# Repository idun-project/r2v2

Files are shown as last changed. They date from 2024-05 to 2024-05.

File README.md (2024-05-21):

## R2V2 - Dual-video switcher & converter for the Commodore 128

This is an open-source project that aims to improve the quality, flexibility, and convenience of the dual-video outputs of the Commodore 128.

In the normal configuration, the C128 has two independent video outputs for the VDC (80-column mode) and the VIC-II (40-column mode) displays. Each display requires its own cable going to its own specific type of monitor input, with the ideal being RGBI input for the 80col display and S-video for the 40col display. You can use two monitors, or you can use a retro monitor (e.g. Commodore 1084) that is manually switchable between two inputs.

With R2V2 installed in a C128, a single port, cable, and monitor input is used for BOTH display modes AND the display mode is switchable using the keyboard or with software control. If you also have the [idun-cartridge](https://github.com/idun-project/idun-cartridge), its software will be able to switch the displays automatically.

### Components

VDC Enhancer (8568) front
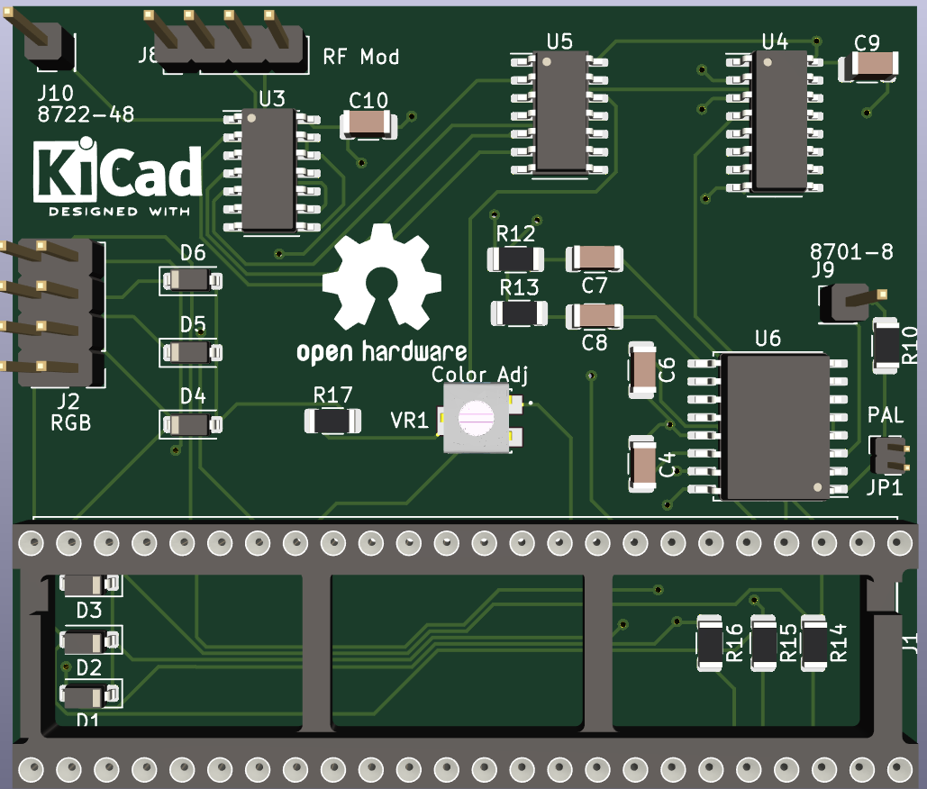
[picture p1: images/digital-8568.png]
VDC enhancer front


VDC Enhancer (8563) back
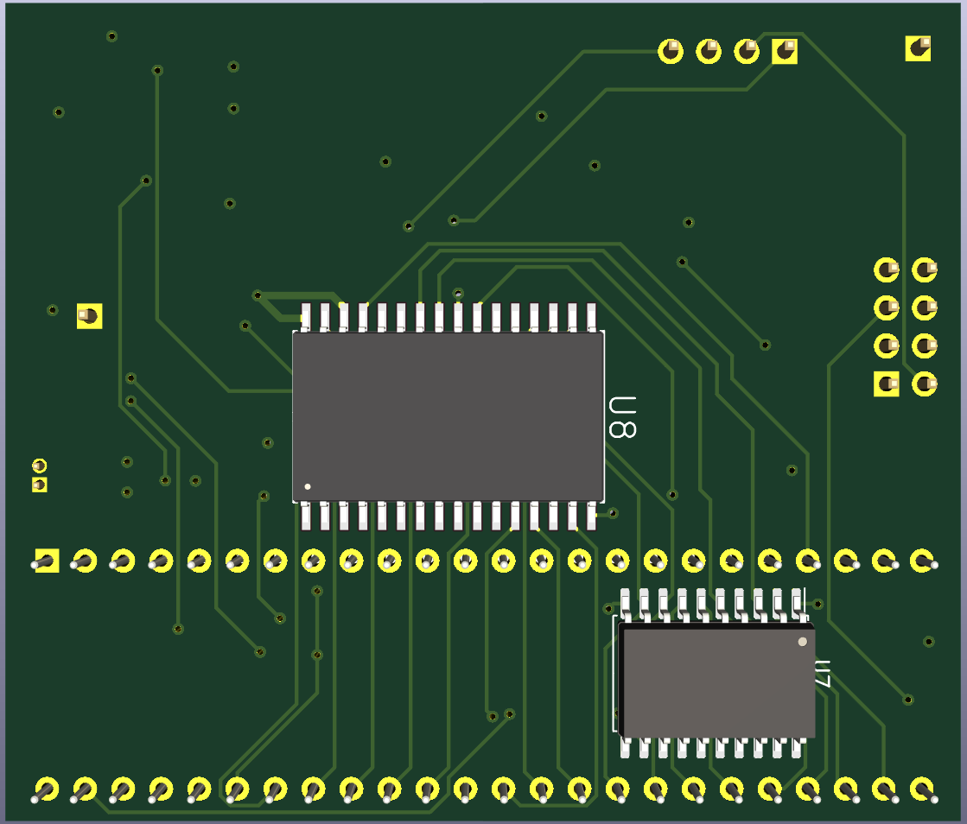
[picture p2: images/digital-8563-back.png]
VDC enhancer back


R2V2 requires two small PCBs installed internally. One sits under the VDC chip, and can optionally include 64KB video RAM expanasion. There are versions for the MOS8563 and the MOS8568 (for C128-DCR). The second PCB installed is from the breakable PCB pictured and is either:

1. An RF modulator replacement, which enhances the 8-pin DIN monitor port plus adds composite monitor and stereo audio outputs (supports 2 SIDs). It can also support switchable **HDMI OUT** from the composite port! (Requires additional components)
2. A modification for the DB-9 monitor port, which outputs analog RGB (rather than RGBI) and can also be used for switchable **HDMI OUT**.

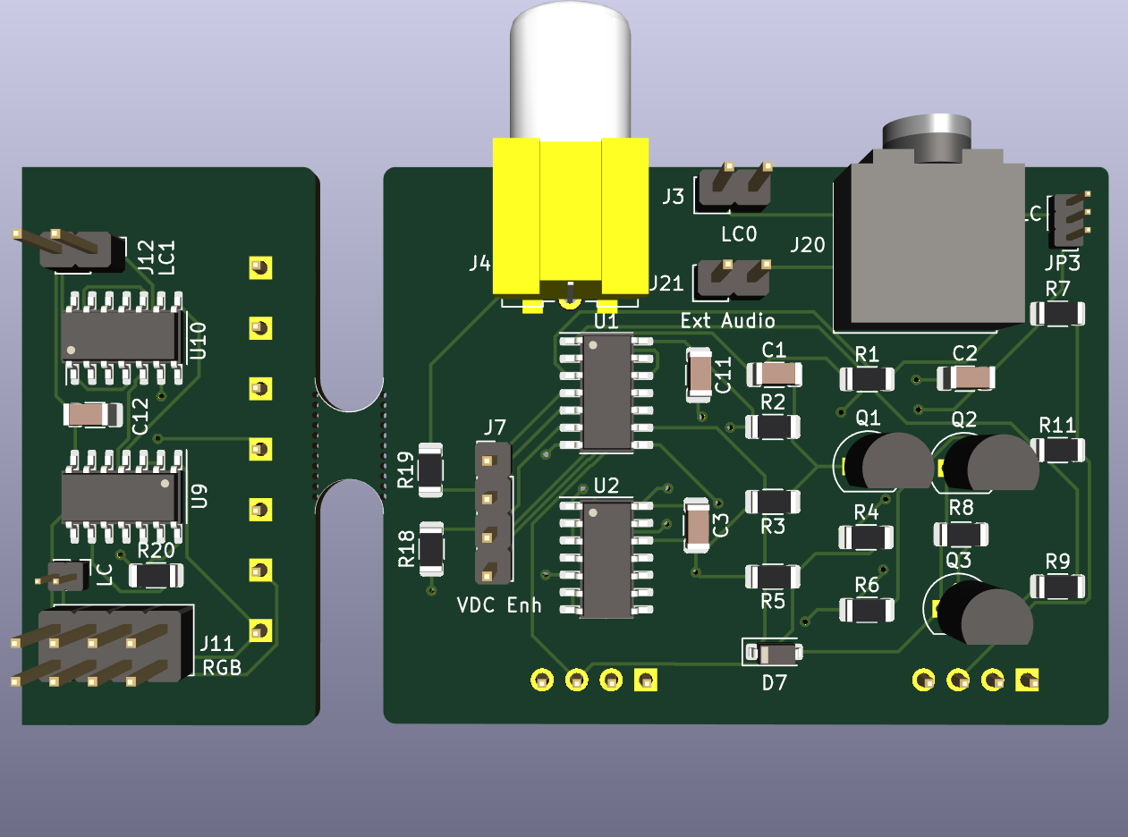
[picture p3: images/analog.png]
2-part analog PCB


### Status

This is an open-source project still in the R&D phase. It is not fully baked, and you should not try to build it _unless you want to contribute to the testing/debugging effort_.

- [x] Prototype PCBs manufactured
    - [x] MOS8568 VDC enhancer
    - [x] MOS8563 VDC enhancer
    - [x] analog board
- [ ] Prototype PCBs assembled
    - [ ] MOS8568 VDC enhancer
    - [ ] MOS8563 VDC enhancer w/o SRAM
    - [ ] MOS8563 VDC enhancer w/ SRAM
    - [ ] RF modulator replacement
    - [ ] DB-9 mod
- [ ] Testing
    - [ ] MOS8568+RF mod S-vid, composite, audio
    - [ ] MOS8563+RF mod S-vid, composite, audio
    - [ ] MOS8563+SRAM
    - [ ] MOS8563+RF mod LumaCode, mono-80c to RGBtoHDMI
    - [ ] MOS8568+DB-9 mod analog RGB
    - [ ] MOS8568+DB-9 mod LumaCode, color-80c to RGBtoHDMI
    - [ ] MOS8563+DB-9 mod LumaCode, color-80c to RGBtoHDMI

### Configurations

Many different configurations are possible, and depends on the kind of monitor you want to use, be it a retro CRT, modern monitor with analog input, or HDMI.

#### For analog monitor inputs

If you intend to use a monitor that supports S-video, you should be able to get good quality color output for both 80col and 40col display modes. Install the VDC enhancer compatible to your system and the RF modulator replacement, then connect the DIN monitor port to your display. You can use the audio on the DIN port, or plug in to the 3.5mm headphone jack.

If you intend to use a monitor that supports composite, you can get decent color 40col and monochrome 80col from the output on the RCA jack. Install the VDC enhancer and the RF modulator replacement, then connect the composite output to your display. Most likely, you will want to use the 3.5mm heahphone jack for audio.

It is possible to install both the RF modulator replacement and the DB-9 mod. If you do this, then you'll have analog RGB (both RGBS and RGBHV) on the DB-9, and that might be what you want for some monitors (e.g. SCART input). You'll have to work out your own switching between displays using this configuration.

#### For digital HDMI monitors

For the absolute best picture quality on modern displays, the R2V2 is combined with the [VIC-II LumaCode](https://github.com/c0pperdragon/LumaCode/wiki/VICIIdizer128-(for-the-C128)) enhancement and an external [RGBtoHDMI](https://github.com/hoglet67/RGBtoHDMI/wiki) video converter/upscaler.

There is a simpler version of the RGBtoHDMI designed by "C0pperdragon" that handles only LumaCode and monochrome video. This version can be used with the composite output on the RF modulator replacement. You will get color 40col and monochrome 80col display modes from a single HDMI input.

If you want the best HDMI experience with color 80col, then you'll need the more sophisticated RGBtoHDMI converter that handles both LumaCode and RGBS. This version connects with a custom cable to the DB-9 port and uses LumaCode for 40col mode and RGBS for 80col mode.

_NOTE_: A firmware patch and profile for the RGBtoHDMI is being developed so that it will automatically switch display modes as your C128 switches between 40/80col modes.

#### 64KB video RAM

The C128-DCR uses a MOS8568 VDC and came with 64KB of VRAM. Just use the MOS8568 version VDC enhancer and you're all set.

Other models of the C128 use a MOS8563 VDC and came with 16KB of VRAM. You must use the MOS8563 version VDC enhancer, and you can _optionally_ install 2 chips on the back of the PCB to upgrade to 64KB of VRAM.

### Build Instructions

TO BE CONTINUED...

### Installation Instructions

TO BE CONTINUED...

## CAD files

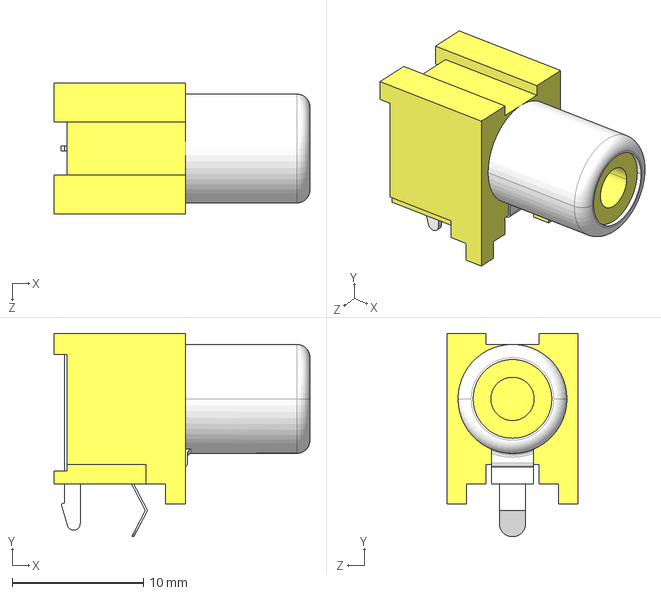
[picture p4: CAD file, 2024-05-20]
r2v2-analog/r2v2_proj_models/CUI_DEVICES_RCJ-044.step
19.5 x 15.5 x 10.0 mm

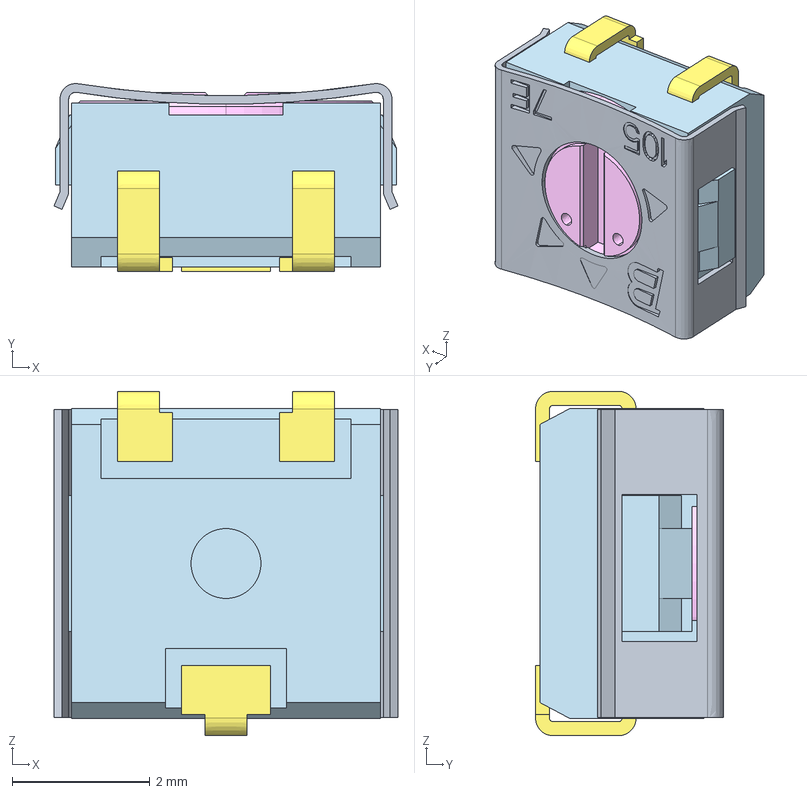
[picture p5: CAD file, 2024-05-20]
r2v2-analog/r2v2_proj_models/3314J-1-501E.step
5.00 x 2.73 x 5.00 mm

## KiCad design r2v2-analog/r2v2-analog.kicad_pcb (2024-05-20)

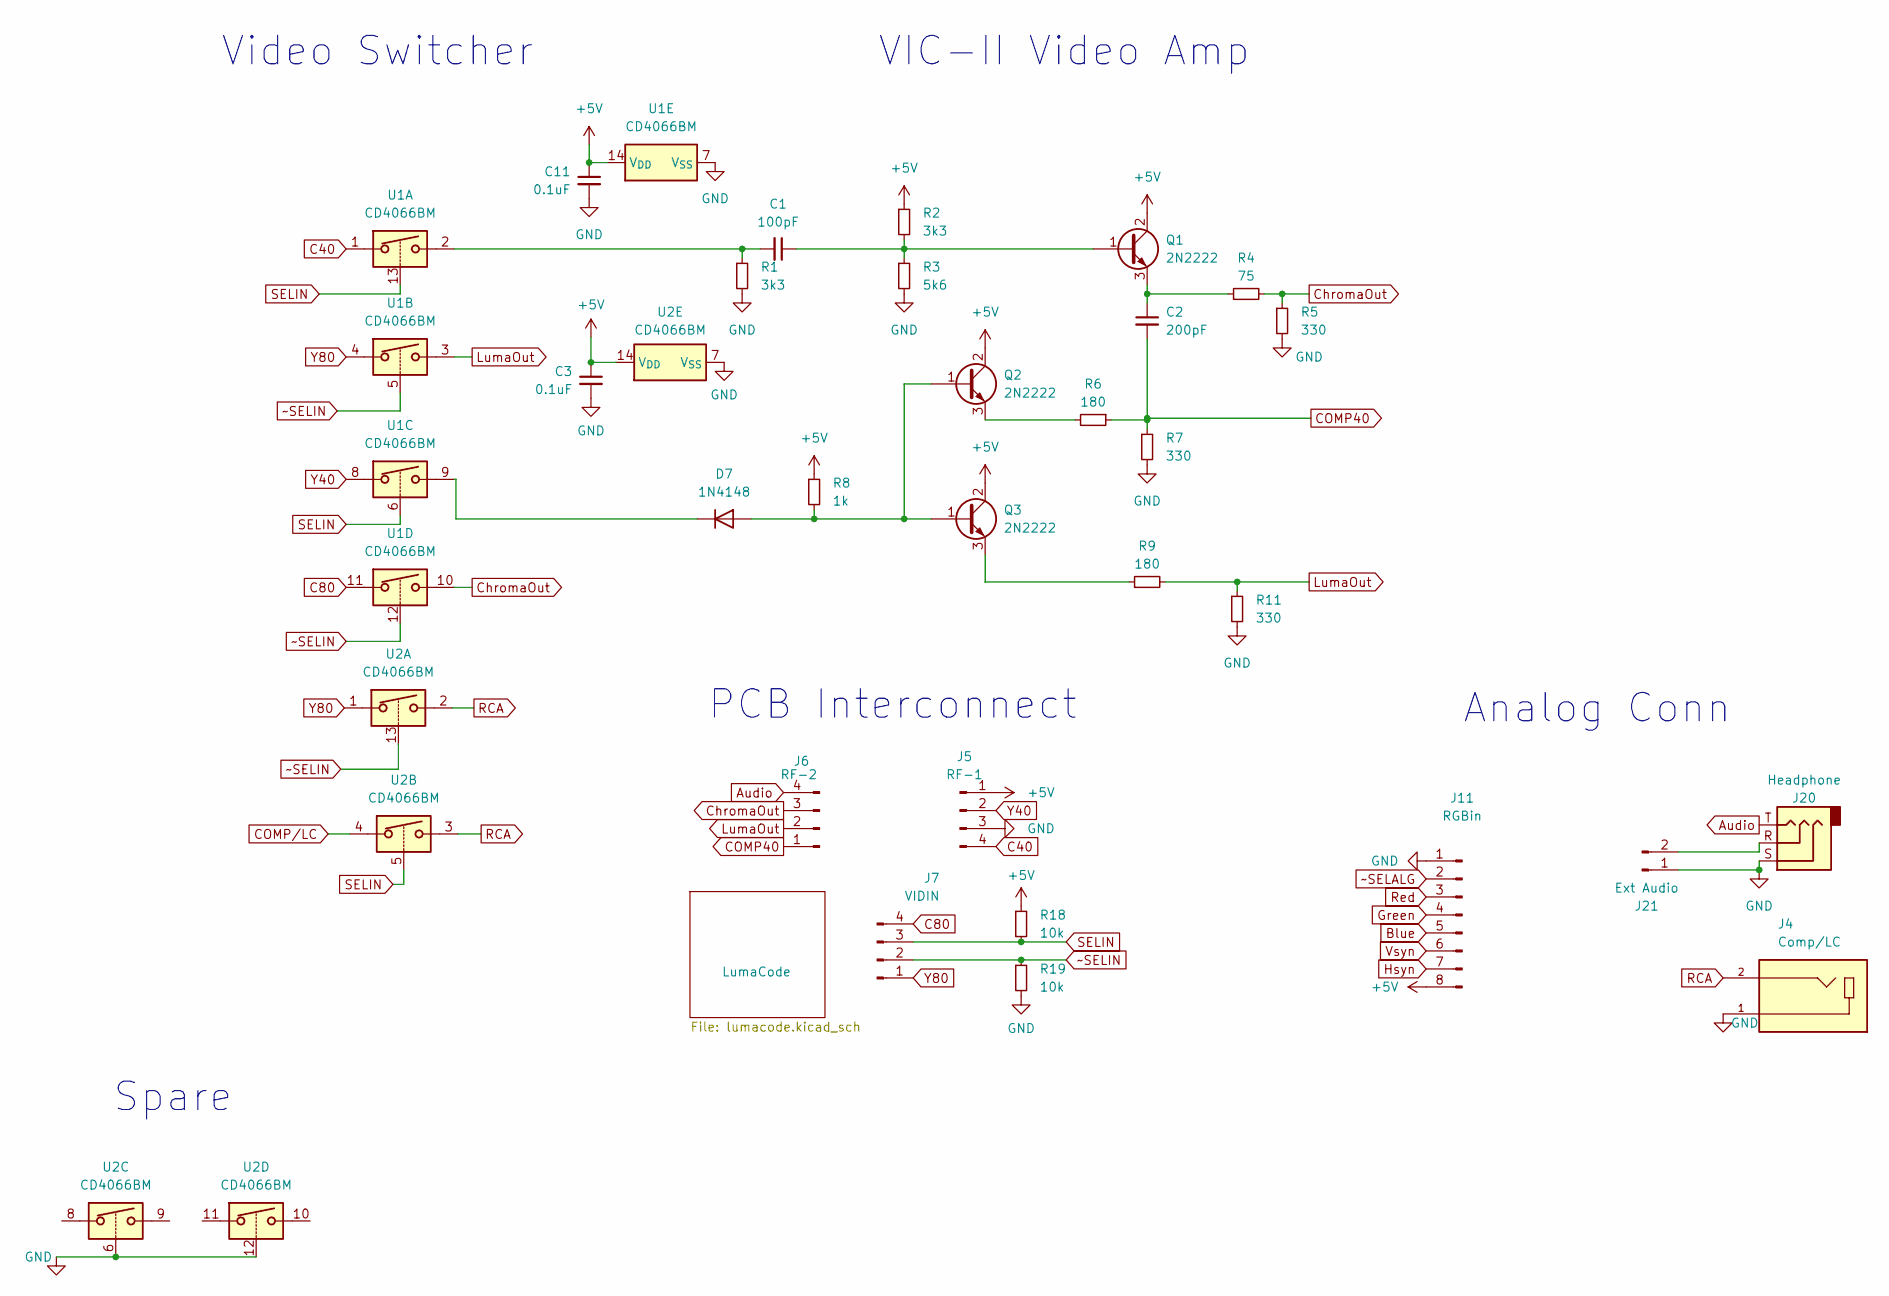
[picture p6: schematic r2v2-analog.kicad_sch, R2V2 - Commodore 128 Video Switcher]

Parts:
C1: 100pF; C_1206_3216Metric
C2: 200pF; C_1206_3216Metric
C3, C11: 0.1uF; C_1206_3216Metric
D7: 1N4148; D_SOD-123
J4: Comp/LC; CUI_RCJ-044; PARTREV 1.02
J5: RF-1; PinHeader_1x04_P2.54mm_Vertical
J6: RF-2; PinHeader_1x04_P2.54mm_Vertical
J7: VIDIN; PinHeader_1x04_P2.54mm_Vertical
J11: RGBin; PinHeader_2x04_P2.54mm_Vertical
J20: Headphone; Jack_3.5mm_CUI_SJ1-3523N_Horizontal
J21: Ext Audio; PinHeader_1x02_P2.54mm_Vertical
Q1, Q2, Q3: 2N2222; TO-92
R1, R2: 3k3; R_1206_3216Metric
R3: 5k6; R_1206_3216Metric
R4: 75; R_1206_3216Metric
R5, R7, R11: 330; R_1206_3216Metric
R6, R9: 180; R_1206_3216Metric
R8: 1k; R_1206_3216Metric
R18, R19: 10k; R_1206_3216Metric
U1, U2: CD4066BM; SO-14_3.9x8.65mm_P1.27mm

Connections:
+5V: C3.1, C11.1, J5.1, J11.8, Q1.2 (C), Q2.2 (C), Q3.2 (C), R2.1, R8.1, R18.1, U1.14 (V_{DD}), U2.14 (V_{DD}); also elsewhere on the board
Audio: J6.4, J20.T
Blue: J11.5; also elsewhere on the board
C40: J5.4, U1.1
C80: J7.4, U1.11
COMP40: C2.2, J6.1, R6.1, R7.1; also elsewhere on the board
COMP/LC: U2.4; also elsewhere on the board
ChromaOut: J6.3, R4.2, R5.1, U1.10
GND: C3.2, C11.2, J4.1, J5.3, J11.1, J20.S, J21.1, R1.2, R3.2, R5.2, R7.2, R11.2, R19.2, U1.7 (V_{SS}), U2.6, U2.7 (V_{SS}), U2.12; also elsewhere on the board
Green: J11.4; also elsewhere on the board
Hsyn: J11.7; also elsewhere on the board
LumaOut: J6.2, R9.2, R11.1, U1.3
unnamed: C1.2, R1.1, U1.2
unnamed: D7.2 (A), Q2.1 (B), Q3.1 (B), R8.2
unnamed: D7.1 (K), U1.9
unnamed: J20.R, J21.2
unnamed: C1.1, Q1.1 (B), R2.2, R3.1
unnamed: C2.1, Q1.3 (E), R4.1
unnamed: Q2.3 (E), R6.2
unnamed: Q3.3 (E), R9.1
RCA: J4.2, U2.2, U2.3
Red: J11.3; also elsewhere on the board
SELIN: J7.3, R18.2, U1.6, U1.13, U2.5
Vsyn: J11.6; also elsewhere on the board
Y40: J5.2, U1.8
Y80: J7.1, U1.4, U2.1
~SELALG: J11.2; also elsewhere on the board
~SELIN: J7.2, R19.1, U1.5, U1.12, U2.13

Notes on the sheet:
Spare
VIC-II Video Amp
Video Switcher
Analog Conn
PCB Interconnect

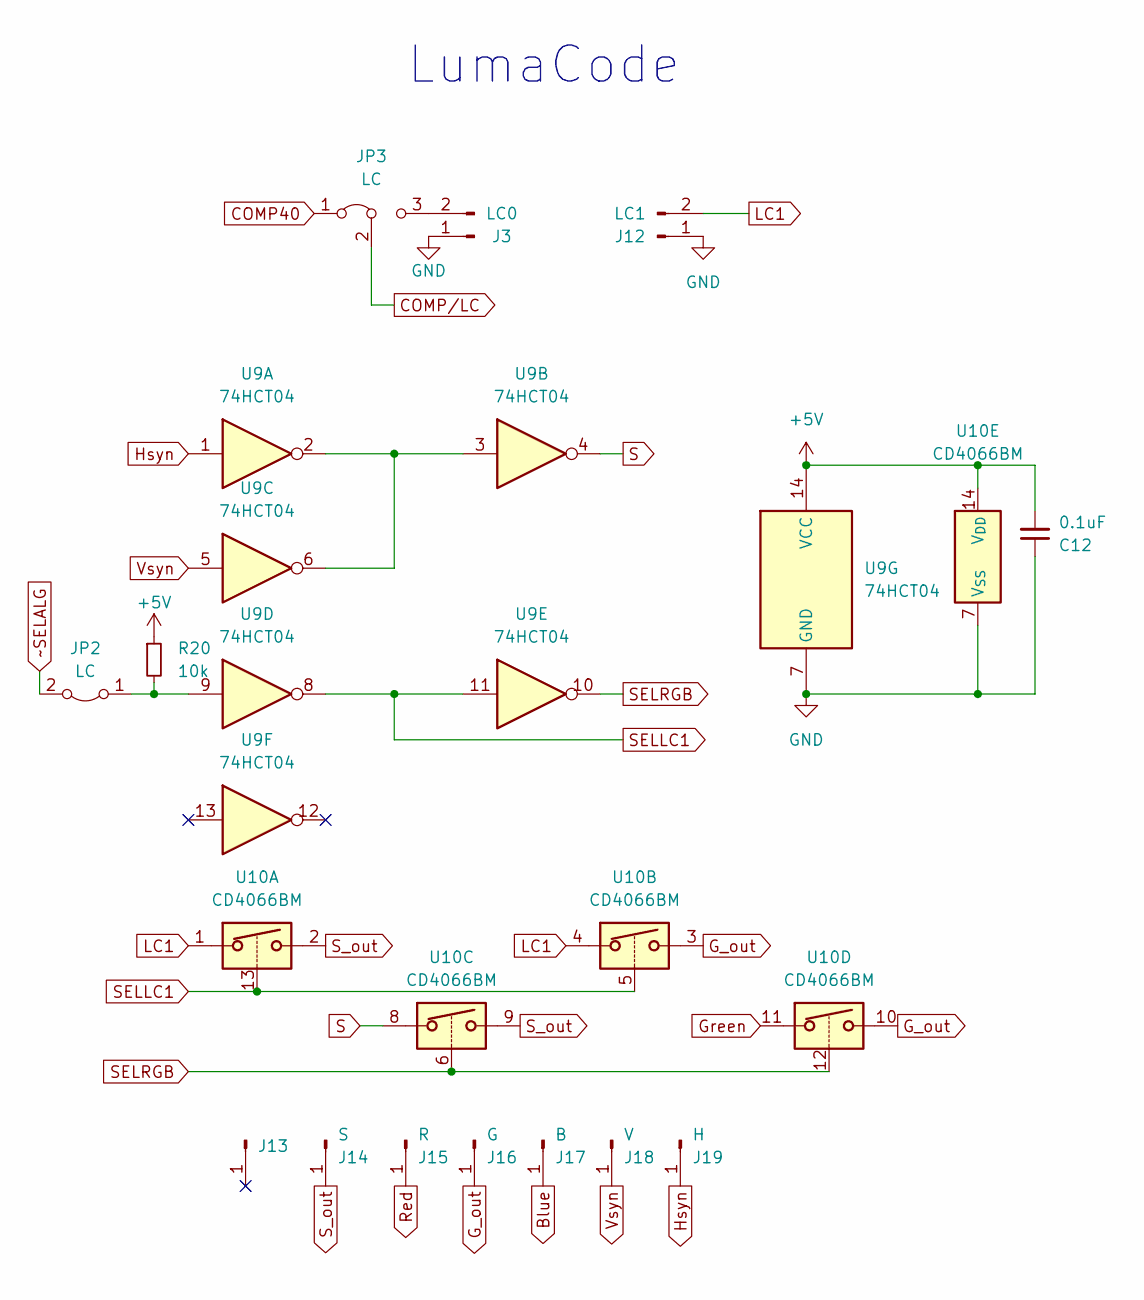
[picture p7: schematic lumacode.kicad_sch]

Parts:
C12: 0.1uF; C_1206_3216Metric
J3: LC0; PinHeader_1x02_P2.54mm_Vertical
J12: LC1; PinHeader_1x02_P2.54mm_Vertical
J13: PinHeader_1x01_P2.54mm_Vertical
J14: S; PinHeader_1x01_P2.54mm_Vertical
J15: R; PinHeader_1x01_P2.54mm_Vertical
J16: G; PinHeader_1x01_P2.54mm_Vertical
J17: B; PinHeader_1x01_P2.54mm_Vertical
J18: V; PinHeader_1x01_P2.54mm_Vertical
J19: H; PinHeader_1x01_P2.54mm_Vertical
JP2: LC; PinHeader_1x02_P1.27mm_Vertical
JP3: LC; PinHeader_1x03_P1.27mm_Vertical
R20: 10k; R_1206_3216Metric
U9: 74HCT04; SO-14_3.9x8.65mm_P1.27mm
U10: CD4066BM; SO-14_3.9x8.65mm_P1.27mm

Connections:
+5V: C12.2, R20.1, U9.14 (VCC), U10.14 (V_{DD}); also elsewhere on the board
Blue: J17.1; also elsewhere on the board
COMP40: JP3.1 (A); also elsewhere on the board
COMP/LC: JP3.2 (C); also elsewhere on the board
GND: C12.1, J3.1, J12.1, U9.7 (GND), U10.7 (V_{SS}); also elsewhere on the board
G_out: J16.1, U10.3, U10.10
Green: U10.11; also elsewhere on the board
Hsyn: J19.1, U9.1; also elsewhere on the board
LC1: J12.2, U10.1, U10.4
unnamed: J3.2, JP3.3 (B)
unnamed: JP2.1 (A), R20.2, U9.9
unnamed: U9.2, U9.3, U9.6
Red: J15.1; also elsewhere on the board
S: U9.4, U10.8
SELLC1: U9.8, U9.11, U10.5, U10.13
SELRGB: U9.10, U10.6, U10.12
S_out: J14.1, U10.2, U10.9
Vsyn: J18.1, U9.5; also elsewhere on the board
~SELALG: JP2.2 (B); also elsewhere on the board

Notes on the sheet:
LumaCode

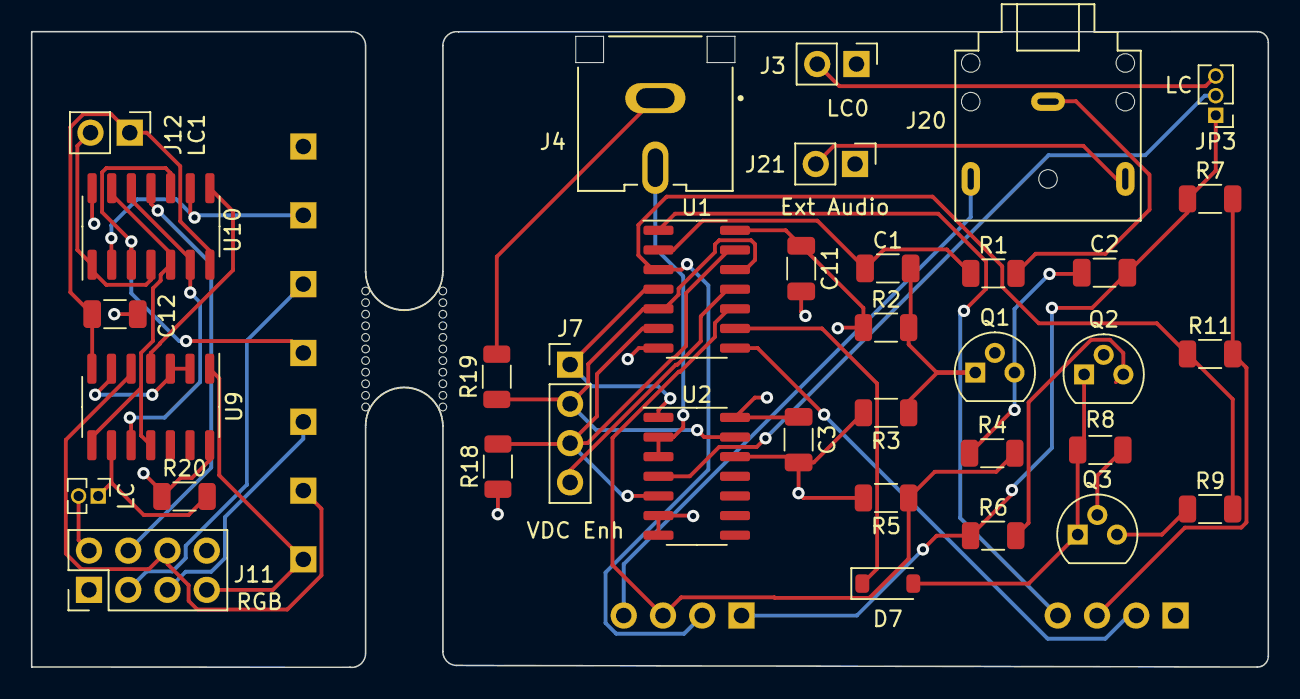
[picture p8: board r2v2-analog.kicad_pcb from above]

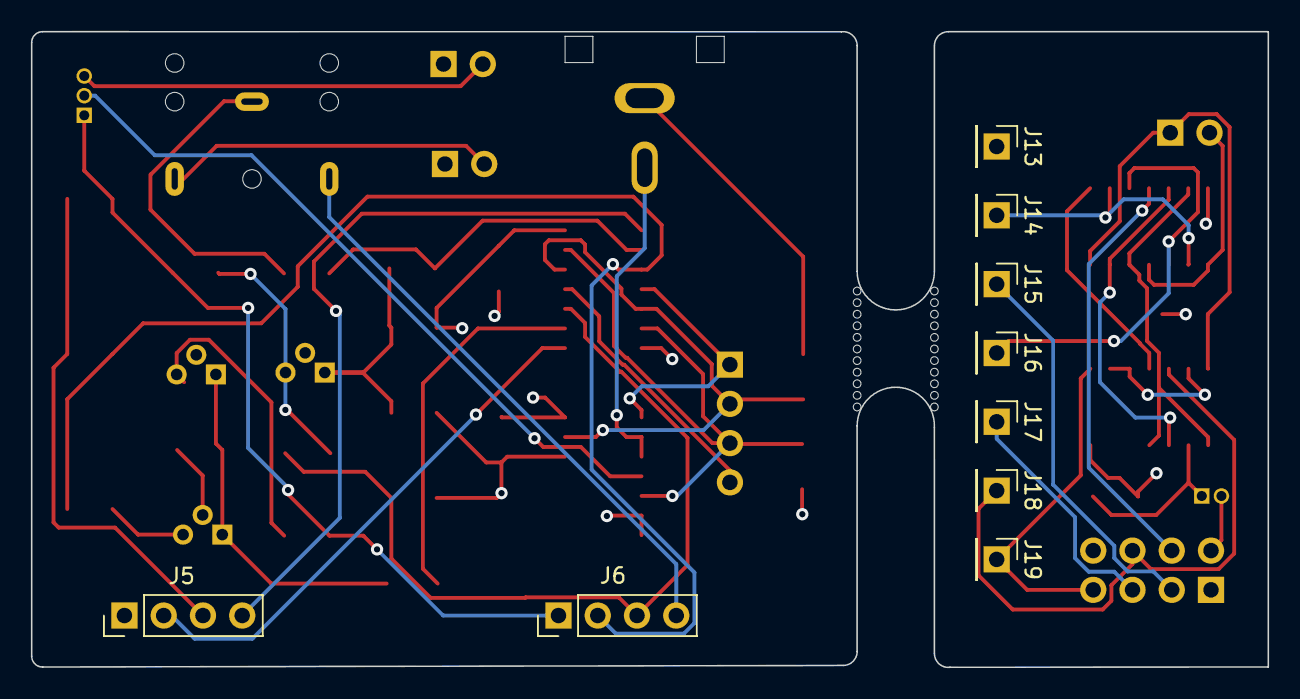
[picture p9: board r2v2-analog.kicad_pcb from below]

Board: 4 copper layers, 80.0 x 41.1 mm, 45 parts (9 on the bottom side), 37 nets.

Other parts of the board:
mouse-bite-5mm-slot: VAL**; mouse-bite-5mm-slot

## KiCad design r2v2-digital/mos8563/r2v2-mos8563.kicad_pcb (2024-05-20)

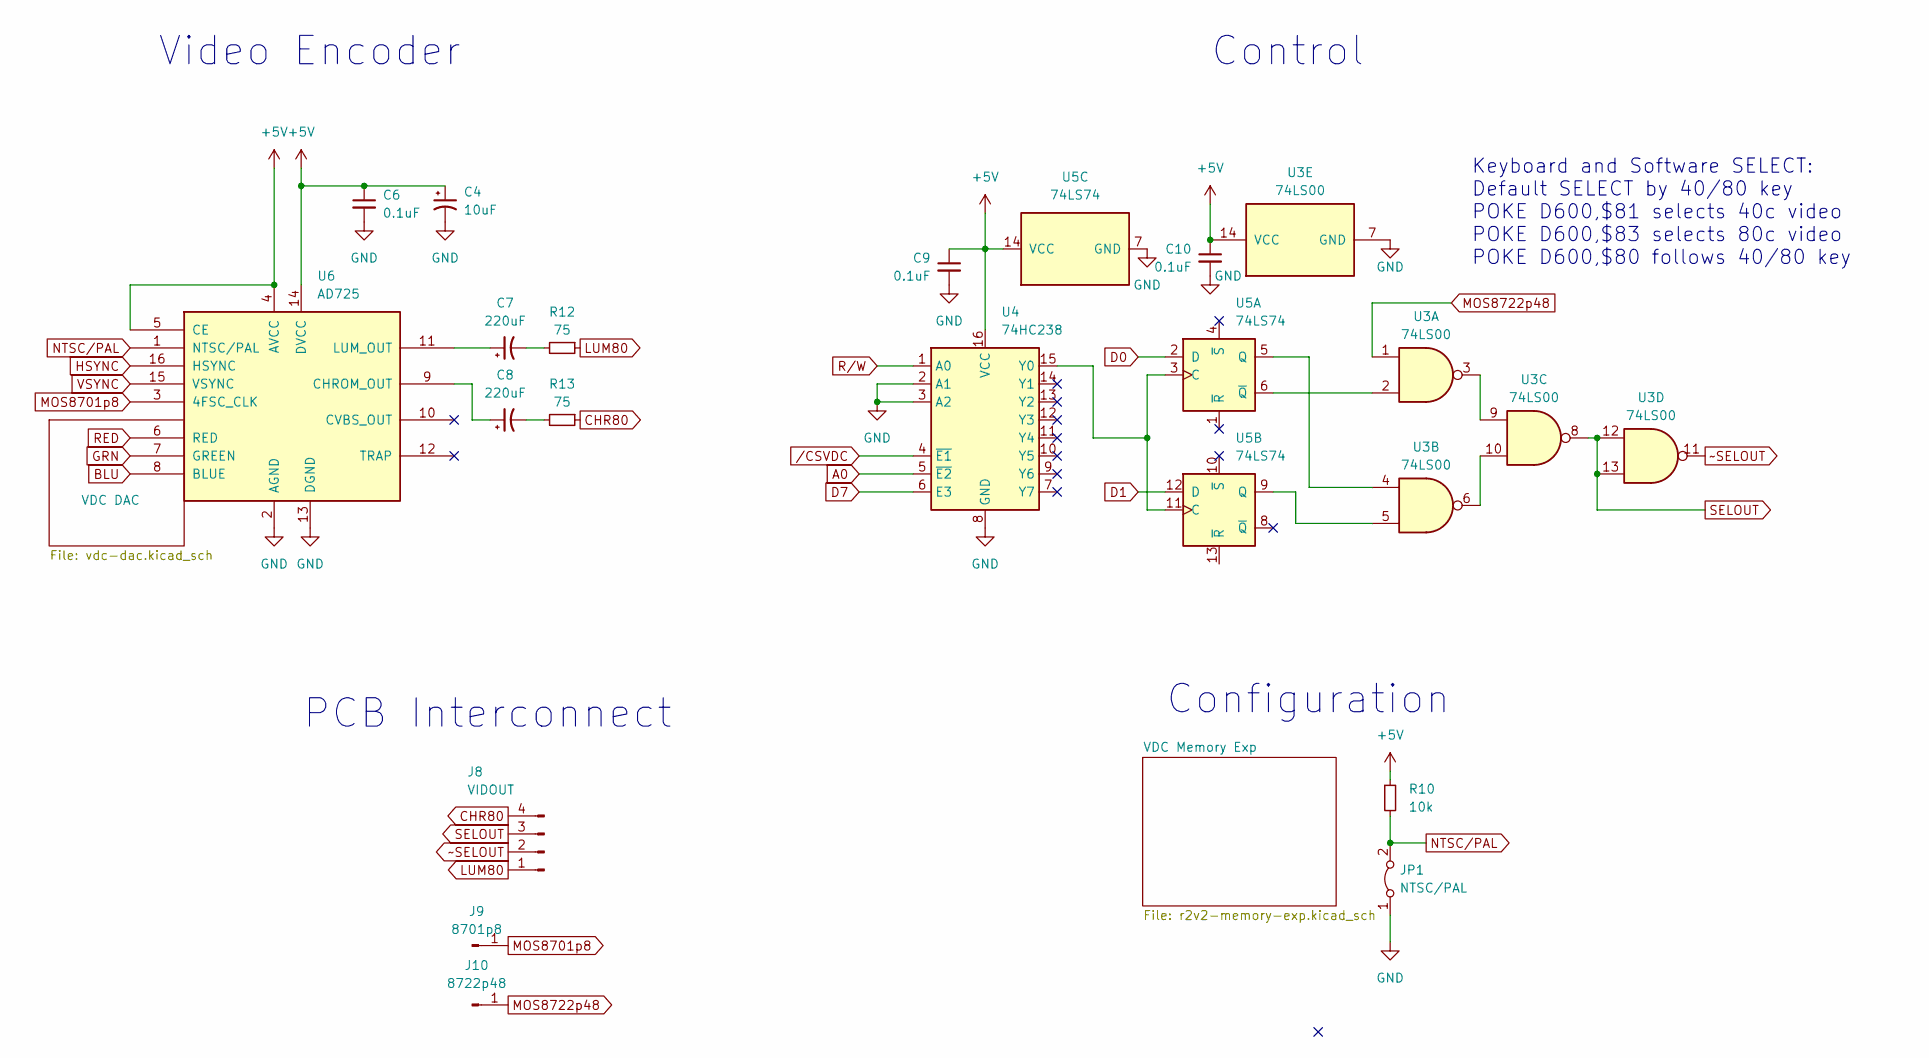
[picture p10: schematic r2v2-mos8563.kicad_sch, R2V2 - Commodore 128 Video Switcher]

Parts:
C4: 10uF; C_1206_3216Metric
C6, C9, C10: 0.1uF; C_1206_3216Metric
C7, C8: 220uF; C_1206_3216Metric
J8: VIDOUT; PinHeader_1x04_P2.54mm_Vertical
J9: 8701p8; PinHeader_1x01_P2.54mm_Vertical
J10: 8722p48; PinHeader_1x01_P2.54mm_Vertical
JP1: NTSC/PAL; PinHeader_1x02_P1.27mm_Vertical
R10: 10k; R_1206_3216Metric
R12, R13: 75; R_1206_3216Metric
U3: 74LS00; SOIC-14_3.9x8.7mm_P1.27mm
U4: 74HC238; SOIC-16_3.9x9.9mm_P1.27mm
U5: 74LS74; SO-14_3.9x8.65mm_P1.27mm
U6: AD725; SOIC-16W_7.5x10.3mm_P1.27mm

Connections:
+5V: C4.1, C6.1, C9.1, C10.1, R10.1, U3.14 (VCC), U4.16 (VCC), U5.14 (VCC), U6.4 (AVCC), U6.5 (CE), U6.14 (DVCC); also elsewhere on the board
A0: U4.5 (~E2); also elsewhere on the board
BLU: U6.8 (BLUE); also elsewhere on the board
CHR80: J8.4, R13.1
D0: U5.2 (D); also elsewhere on the board
D1: U5.12 (D); also elsewhere on the board
D7: U4.6 (E3)
GND: C4.2, C6.2, C9.2, C10.2, JP1.1 (A), U3.7 (GND), U4.2 (A1), U4.3 (A2), U4.8 (GND), U5.7 (GND), U6.2 (AGND), U6.13 (DGND); also elsewhere on the board
GRN: U6.7 (GREEN); also elsewhere on the board
HSYNC: U6.16 (HSYNC); also elsewhere on the board
LUM80: J8.1, R12.1
MOS8701p8: J9.1, U6.3 (4FSC_CLK)
MOS8722p48: J10.1, U3.1
NTSC/PAL: JP1.2 (B), R10.2, U6.1 (NTSC/PAL)
unnamed: C7.2, R12.2
unnamed: C8.2, R13.2
unnamed: U3.3, U3.9
unnamed: U3.6, U3.10
unnamed: U4.15 (Y0), U5.3 (C), U5.11 (C)
unnamed: U3.4, U5.5 (Q)
unnamed: U3.2, U5.6 (~Q)
unnamed: U3.5, U5.9 (Q)
unnamed: C8.1, U6.9 (CHROM_OUT)
unnamed: C7.1, U6.11 (LUM_OUT)
RED: U6.6 (RED); also elsewhere on the board
R/W: U4.1 (A0); also elsewhere on the board
SELOUT: J8.3, U3.8, U3.12, U3.13
VSYNC: U6.15 (VSYNC); also elsewhere on the board
/CSVDC: U4.4 (~E1); also elsewhere on the board
~SELOUT: J8.2, U3.11; also elsewhere on the board

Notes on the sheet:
Control
Video Encoder
Keyboard and Software SELECT: Default SELECT by 40/80 key POKE D600,$81 selects 40c video POKE D600,$83 selects 80c video POKE D600,$80 follows 40/80 key
Configuration
PCB Interconnect

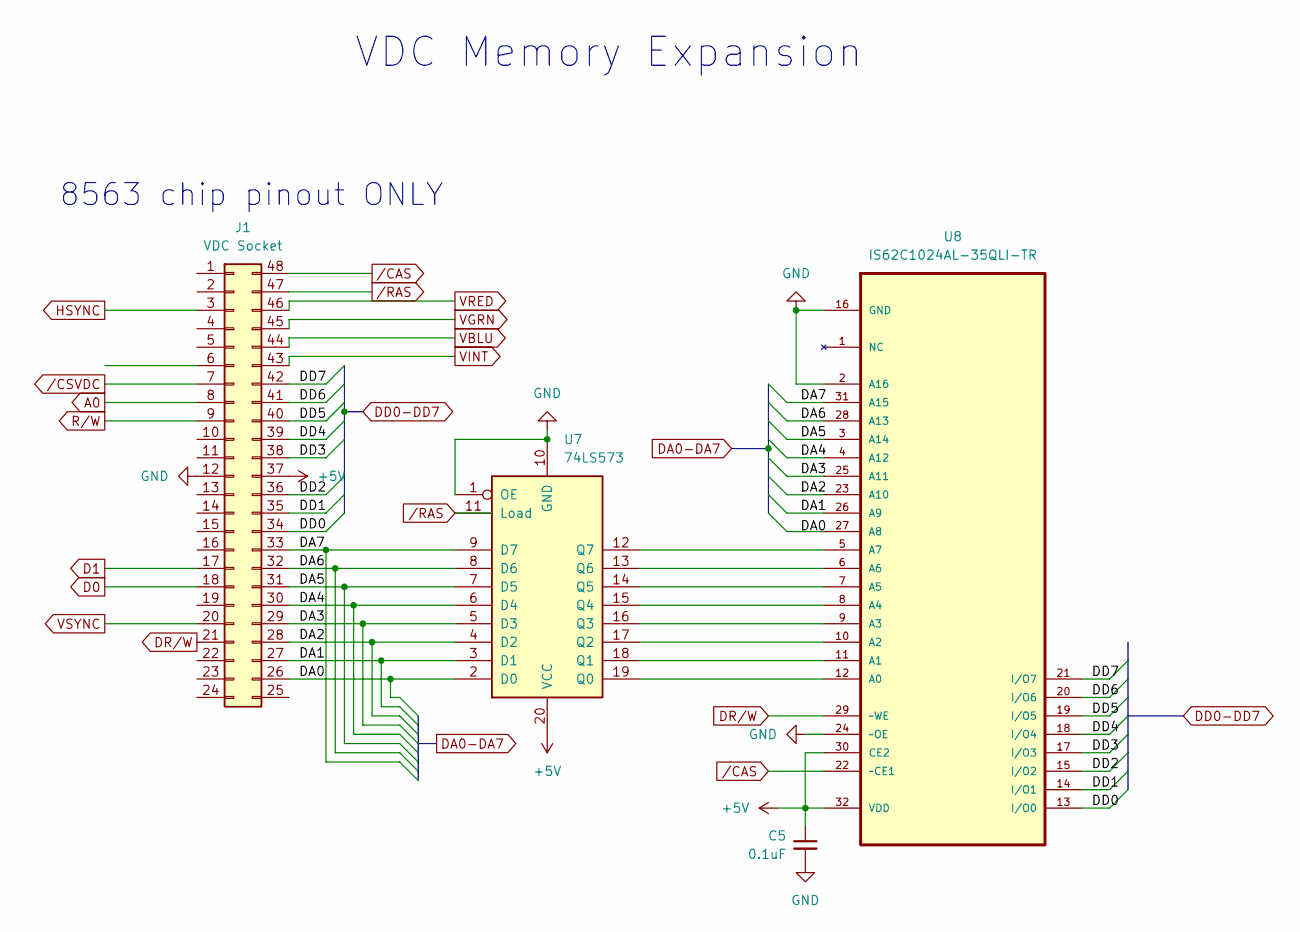
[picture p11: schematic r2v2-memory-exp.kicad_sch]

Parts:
C5: 0.1uF; C_1206_3216Metric
J1: VDC Socket; DIP-48_W15.24mm_Socket
U7: 74LS573; SOIC-20W_7.5x12.8mm_P1.27mm
U8: IS62C1024AL-35QLI-TR; SOIC127P1412X305-32N; MPN IS62C1024AL-35QLI-TR

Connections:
+5V: C5.1, J1.37, U7.20 (VCC), U8.30 (CE2), U8.32 (VDD); also elsewhere on the board
/VDC Memory Exp/DA0: J1.26, U7.2 (D0)
/VDC Memory Exp/DA1: J1.27, U7.3 (D1), U8.26 (A9)
/VDC Memory Exp/DA2: J1.28, U7.4 (D2), U8.23 (A10)
/VDC Memory Exp/DA3: J1.29, U7.5 (D3), U8.25 (A11)
/VDC Memory Exp/DA4: J1.30, U7.6 (D4), U8.4 (A12)
/VDC Memory Exp/DA5: J1.31, U7.7 (D5), U8.3 (A14)
/VDC Memory Exp/DA6: J1.32, U7.8 (D6), U8.28 (A13)
/VDC Memory Exp/DA7: J1.33, U7.9 (D7), U8.31 (A15)
/VDC Memory Exp/DD0: J1.34, U8.13 (I/O0)
/VDC Memory Exp/DD1: J1.35, U8.14 (I/O1)
/VDC Memory Exp/DD2: J1.36, U8.15 (I/O2)
/VDC Memory Exp/DD3: J1.38, U8.17 (I/O3)
/VDC Memory Exp/DD4: J1.39, U8.18 (I/O4)
/VDC Memory Exp/DD5: J1.40, U8.19 (I/O5)
/VDC Memory Exp/DD6: J1.41, U8.20 (I/O6)
/VDC Memory Exp/DD7: J1.42, U8.21 (I/O7)
A0: J1.8; also elsewhere on the board
D0: J1.18; also elsewhere on the board
D1: J1.17; also elsewhere on the board
DR/W: J1.21, U8.29 (~WE)
GND: C5.2, J1.12, U7.1 (OE), U7.10 (GND), U8.2 (A16), U8.16 (GND), U8.24 (~OE); also elsewhere on the board
HSYNC: J1.3; also elsewhere on the board
unnamed: U7.19 (Q0), U8.12 (A0)
unnamed: U7.18 (Q1), U8.11 (A1)
unnamed: U7.17 (Q2), U8.10 (A2)
unnamed: U7.16 (Q3), U8.9 (A3)
unnamed: U7.15 (Q4), U8.8 (A4)
unnamed: U7.14 (Q5), U8.7 (A5)
unnamed: U7.13 (Q6), U8.6 (A6)
unnamed: U7.12 (Q7), U8.5 (A7)
R/W: J1.9; also elsewhere on the board
VBLU: J1.44; also elsewhere on the board
VGRN: J1.45; also elsewhere on the board
VINT: J1.43; also elsewhere on the board
VRED: J1.46; also elsewhere on the board
VSYNC: J1.20; also elsewhere on the board
/CAS: J1.48, U8.22 (~CE1)
/CSVDC: J1.7; also elsewhere on the board
/RAS: J1.47, U7.11 (Load)

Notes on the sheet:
8563 chip pinout ONLY
VDC Memory Expansion

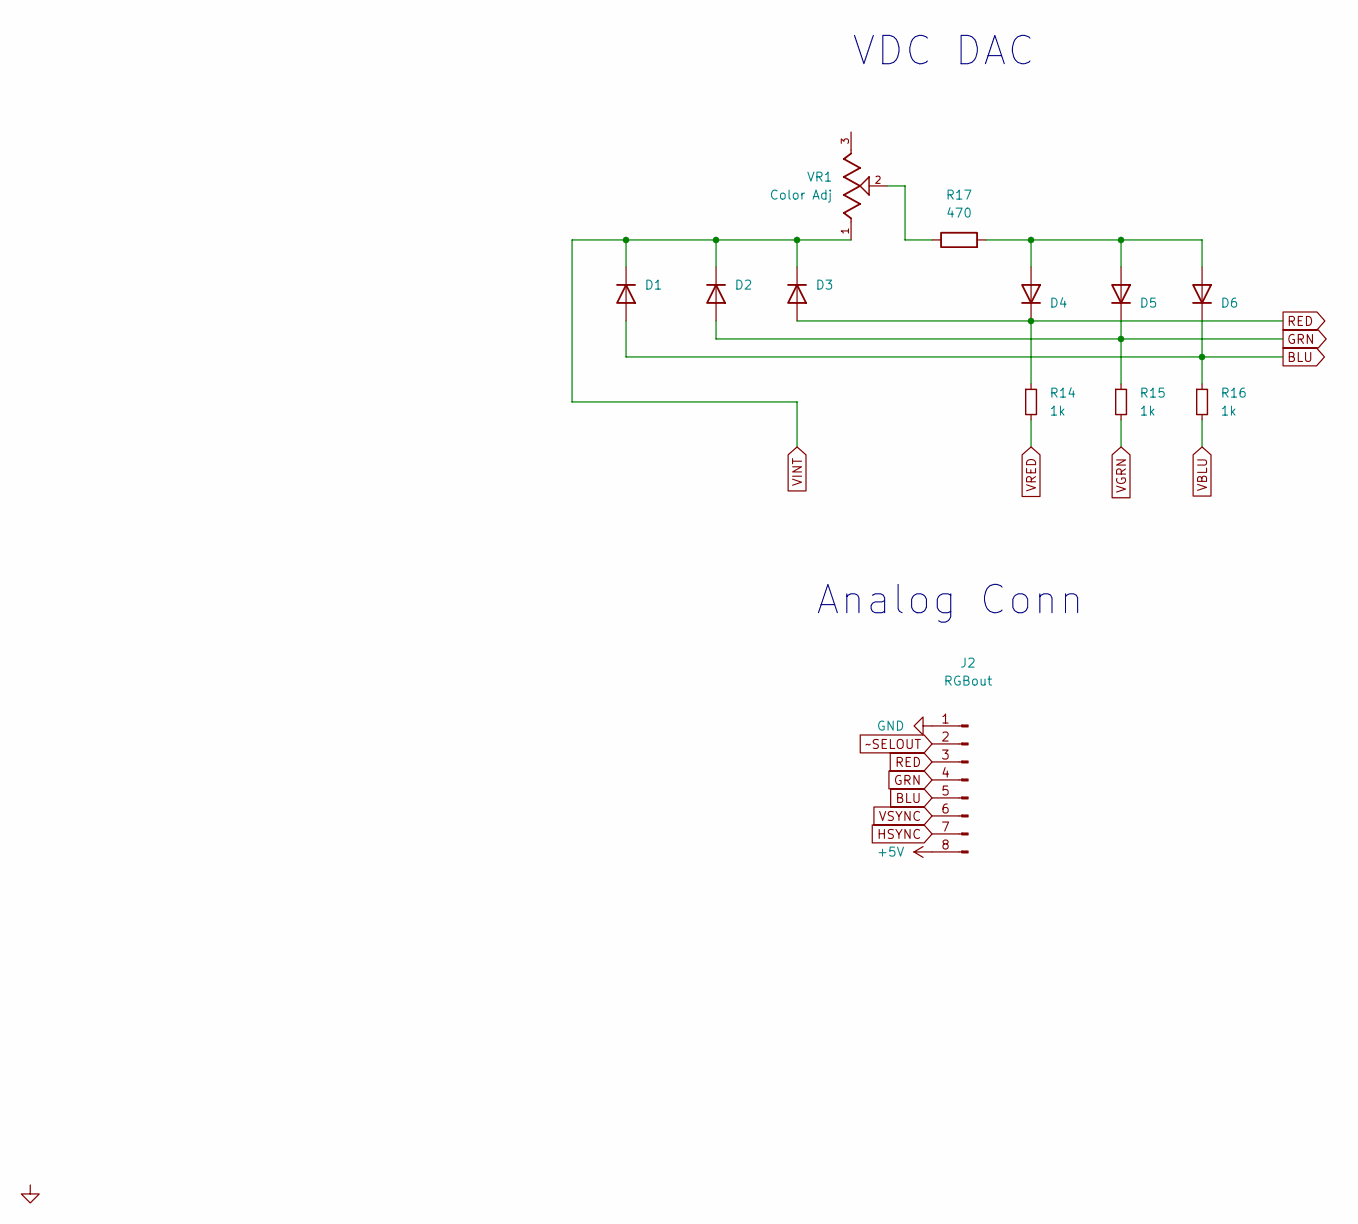
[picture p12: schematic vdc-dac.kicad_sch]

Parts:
D1, D2, D3, D4, D5, D6: 1N4148W; D_SOD-123
J2: RGBout; PinHeader_2x04_P2.54mm_Vertical
R14, R15, R16: 1k; R_1206_3216Metric
R17: 470; R_1206_3216Metric
VR1: Color Adj; TRIM_3314J-1-501E

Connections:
+5V: J2.8; also elsewhere on the board
BLU: D1.2 (A), D6.1 (K), J2.5, R16.1; also elsewhere on the board
GND: J2.1; also elsewhere on the board
GRN: D2.2 (A), D5.1 (K), J2.4, R15.1; also elsewhere on the board
HSYNC: J2.7; also elsewhere on the board
unnamed: D4.2 (A), D5.2 (A), D6.2 (A), R17.2
unnamed: R17.1, VR1.2
RED: D3.2 (A), D4.1 (K), J2.3, R14.1; also elsewhere on the board
VBLU: R16.2; also elsewhere on the board
VGRN: R15.2; also elsewhere on the board
VINT: D1.1 (K), D2.1 (K), D3.1 (K), VR1.1; also elsewhere on the board
VRED: R14.2; also elsewhere on the board
VSYNC: J2.6; also elsewhere on the board
~SELOUT: J2.2; also elsewhere on the board

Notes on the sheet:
VDC DAC
Analog Conn

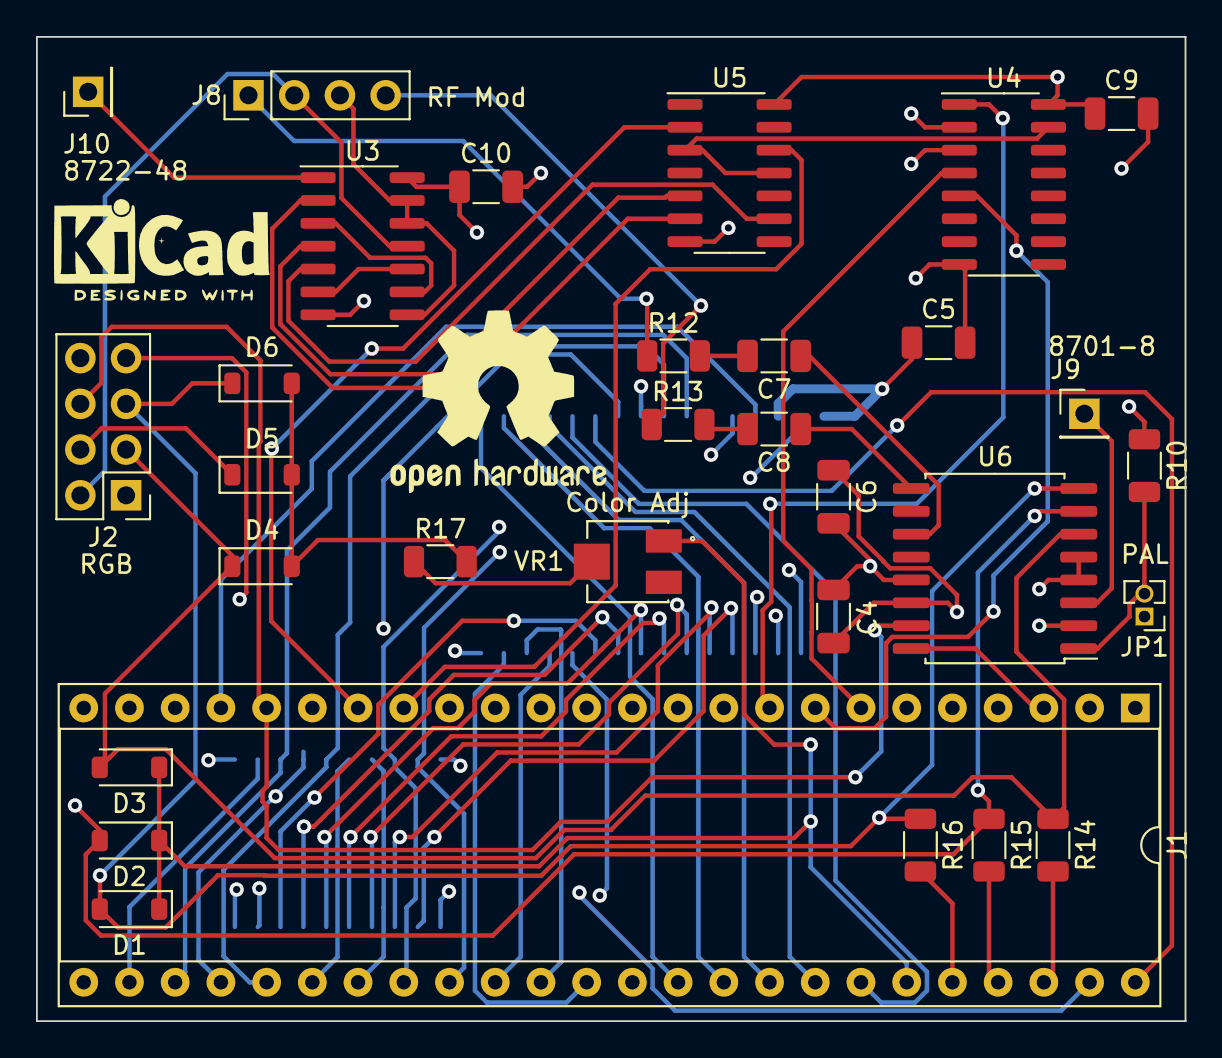
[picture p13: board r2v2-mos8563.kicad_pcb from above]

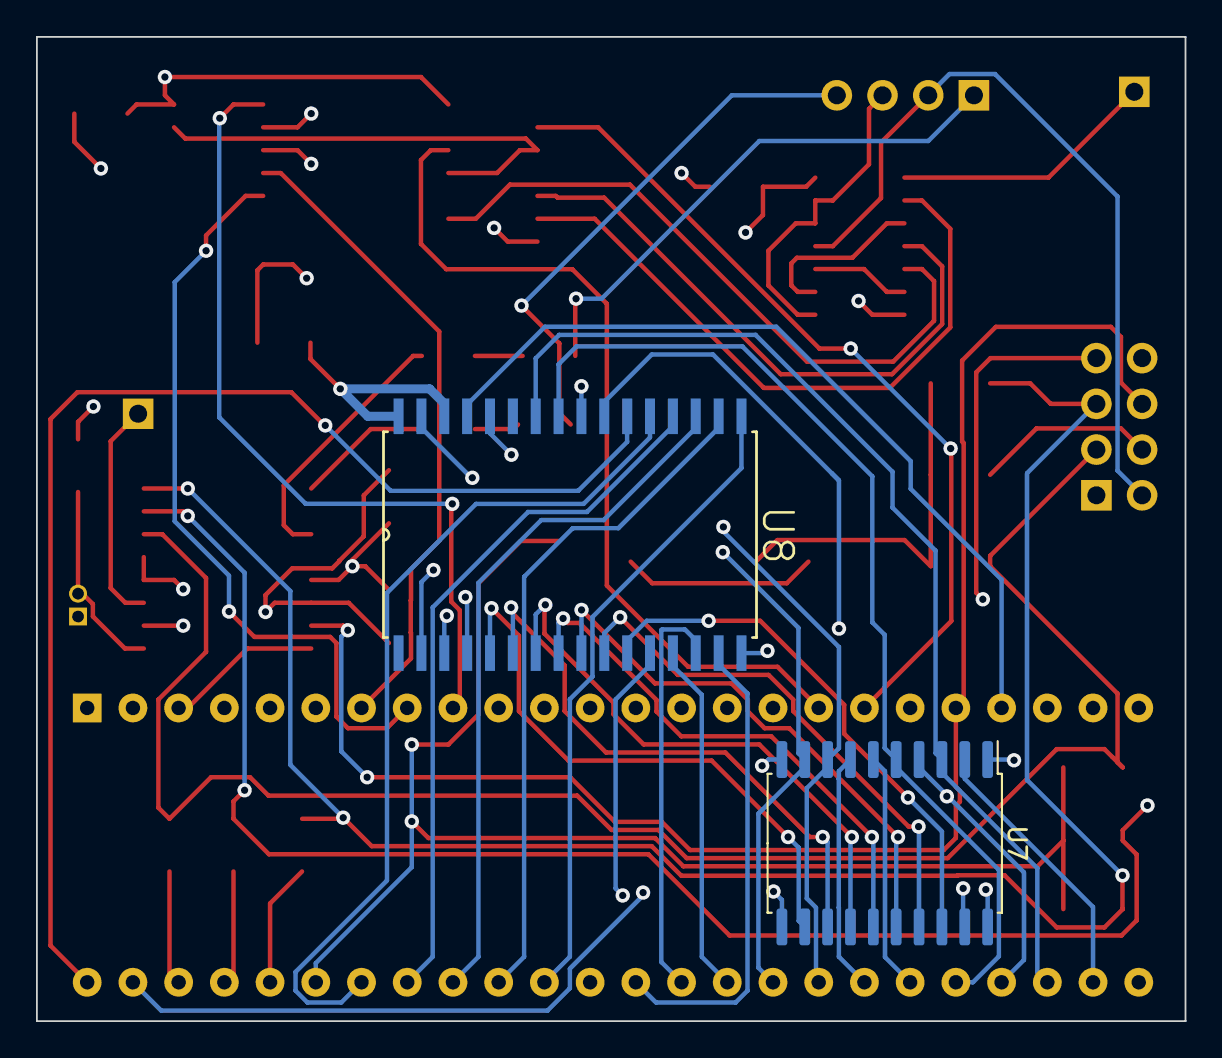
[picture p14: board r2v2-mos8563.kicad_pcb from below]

Board: 4 copper layers, 63.8 x 54.7 mm, 33 parts (2 on the bottom side), 62 nets.

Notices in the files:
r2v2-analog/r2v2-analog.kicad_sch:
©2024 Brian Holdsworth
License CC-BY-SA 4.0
